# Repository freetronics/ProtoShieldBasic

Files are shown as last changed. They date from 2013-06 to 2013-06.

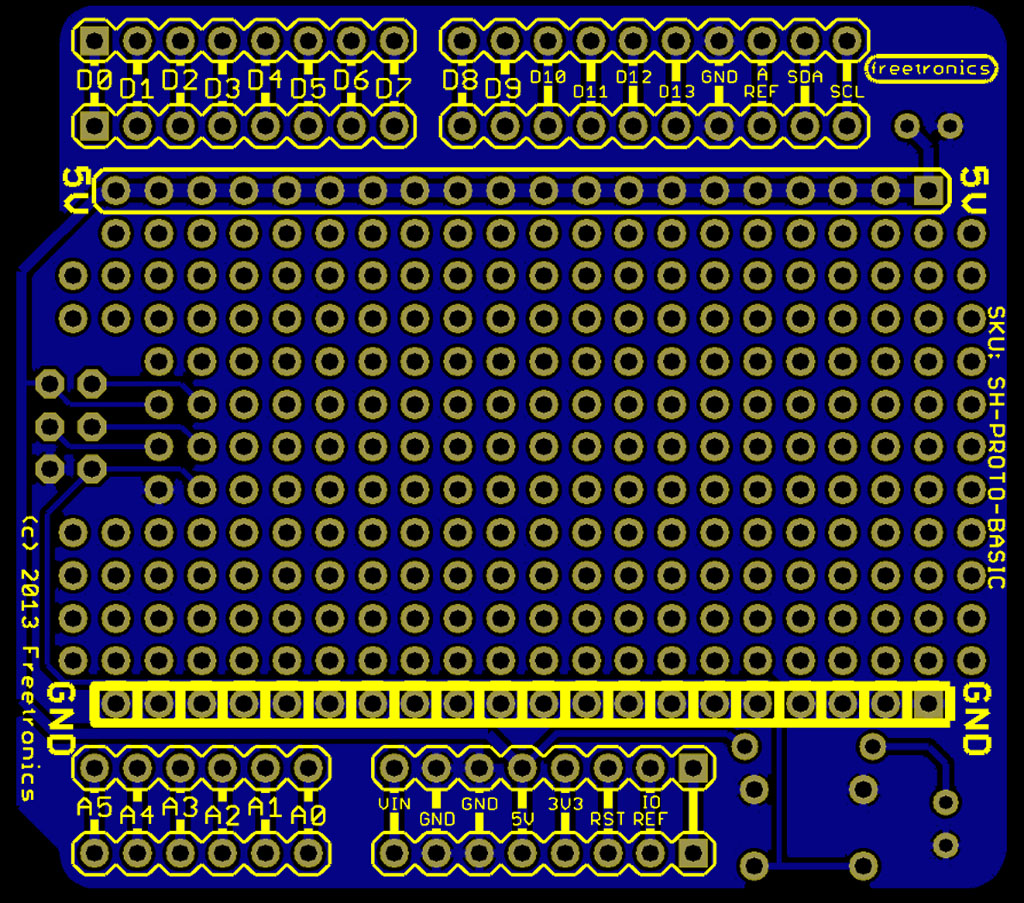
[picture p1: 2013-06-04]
docs/SH-PROTO-BASIC-bottom.jpg

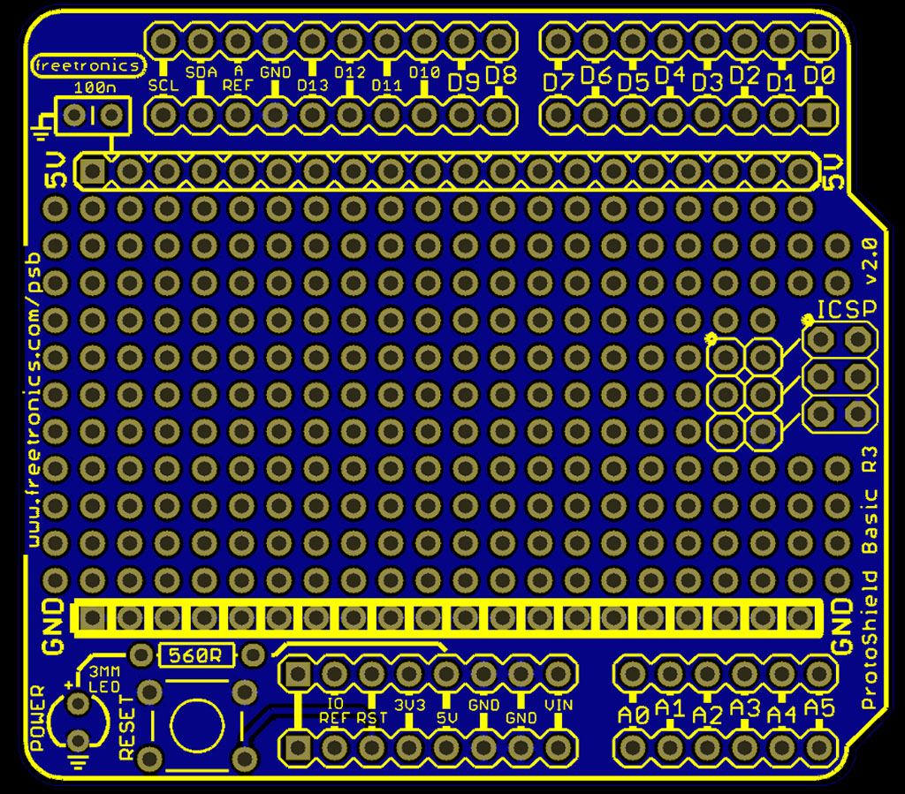
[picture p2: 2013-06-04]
docs/SH-PROTO-BASIC-top.jpg

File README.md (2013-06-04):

Freetronics ProtoShieldBasic
==============================
Copyright 2013 Freetronics Pty Ltd  
Freetronics site:  www.freetronics.com  
Freetronics email: info@freetronics.com  

A minimalist general-purpose prototyping shield for the Arduino
Uno, Freetronics Eleven, and other compatible boards based on the same
header format.

This design is intended to maximise prototyping area by extending the
plain pads right to the ends of the board, which also makes it easier
to fit horizontal PCB-mount sockets that need to overlap the edge.

Note that this design is intended for simple fabrication and assembly,
and does not have many of the features of other prototyping shields
such as the "ProtoShield Pro" (also available from Freetronics) such as
general-purpose LEDs.

Features:

 * Pads for reset button connected to Arduino reset pin.
 * Pads for 100nF smoothing capacitor.
 * Pads for "power on" LED and current-limiting resistor.
 * Parts overlay on both the top and the bottom so you can see what you
   are connecting without having to keep turning the board over.

More information is available at:

  http://www.freetronics.com/psb

INSTALLATION
------------
The design is saved as an EAGLE project. EAGLE PCB design software is
available from www.cadsoftusa.com free for non-commercial use. To use
this project download it and place the directory containing these files
into the "eagle" directory on your computer. Then open EAGLE and
navigate to Projects -> eagle -> ProtoShieldBasic.

DISTRIBUTION
------------
The specific terms of distribution of this project are governed by the
license referenced below.

LICENSE
-------
Licensed under the TAPR Open Hardware License (www.tapr.org/OHL).
The "license" folder within this repository also contains a copy of
this license in plain text format.

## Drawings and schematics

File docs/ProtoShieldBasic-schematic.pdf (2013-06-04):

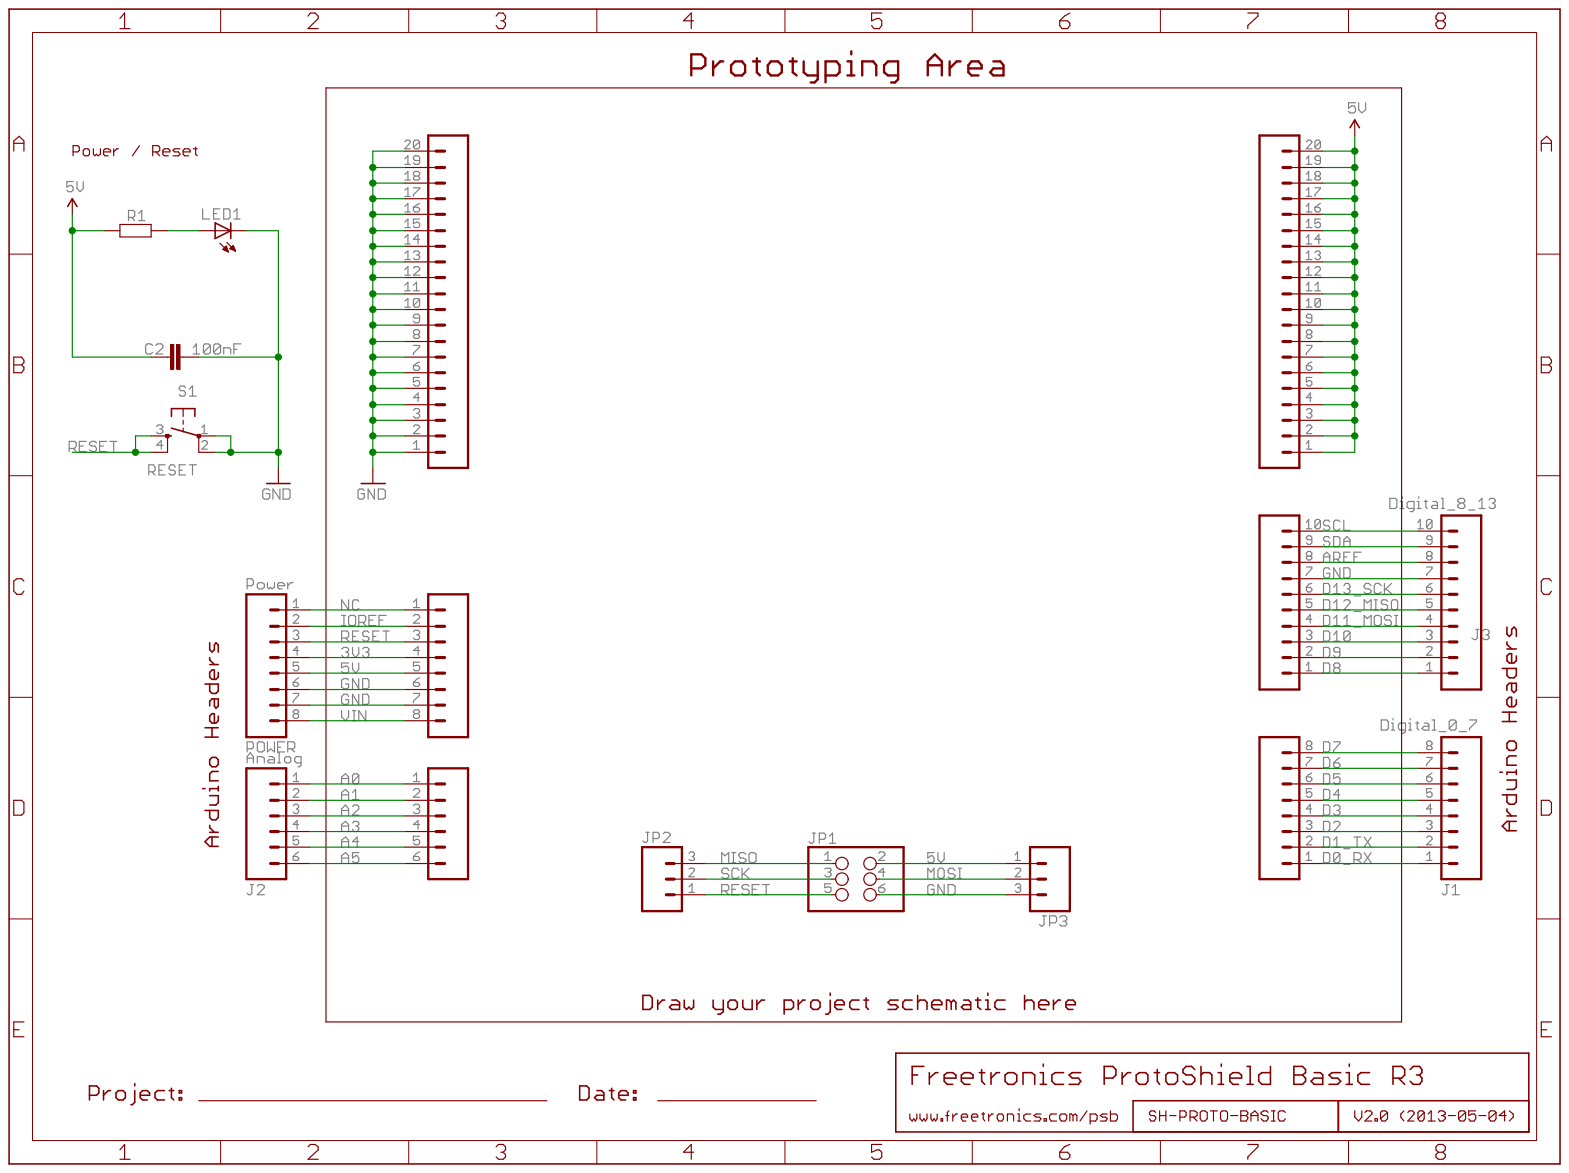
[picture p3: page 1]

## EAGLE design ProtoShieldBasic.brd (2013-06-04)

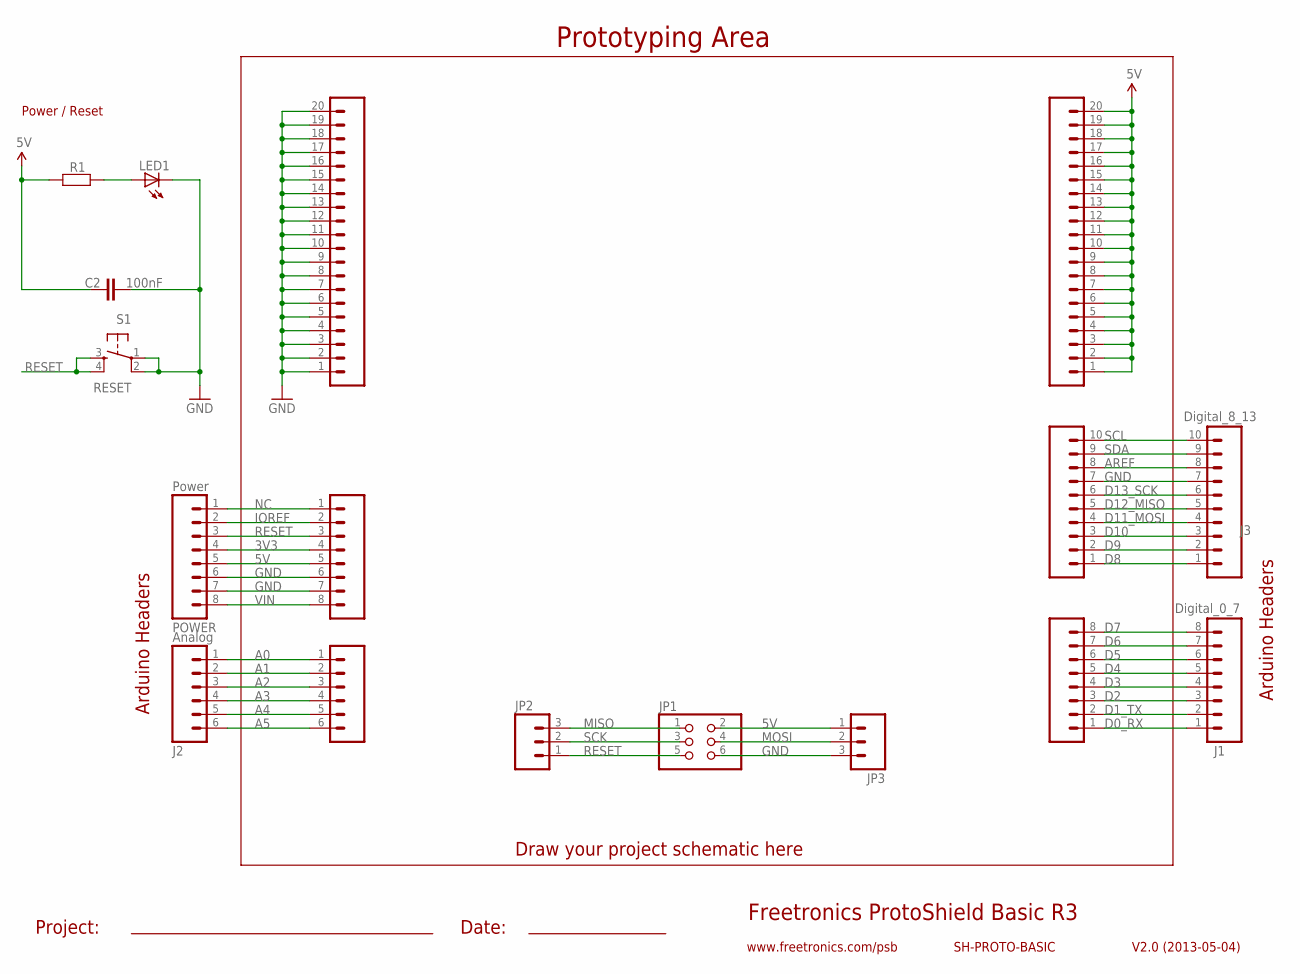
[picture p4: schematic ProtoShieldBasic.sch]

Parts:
C2: 100nF; CAP-PTH-SMALL
J1: Digital_0_7; 1X08
J2: Analog; 1X06
J3: Digital_8_13; 1X10
JP1: PINHD-2X3; 2X03
JP2, JP3: M03PTH; 1X03
LED1: LED3MM
PADS_5V: M20; 1X20
PADS_GND: M20; 1X20
POWER: Power; 1X08
R1: RESISTORPTH1; AXIAL-0.3
S1: RESET; TACTILE-PTH
SL1: Digital_0_7; 1X08
SL2: Analog; 1X06
SL3: Digital_8_13; 1X10
SLP: Power; 1X08

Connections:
3V3: POWER.4, SLP.4
5V: C2.1, JP1.2, JP3.1, PADS_5V.1, PADS_5V.2, PADS_5V.3, PADS_5V.4, PADS_5V.5, PADS_5V.6, PADS_5V.7, PADS_5V.8, PADS_5V.9, PADS_5V.10, PADS_5V.11, PADS_5V.12, PADS_5V.13, PADS_5V.14, PADS_5V.15, PADS_5V.16, PADS_5V.17, PADS_5V.18, PADS_5V.19, PADS_5V.20, POWER.5, R1.P$1 (1), SLP.5
A0: J2.1, SL2.1
A1: J2.2, SL2.2
A2: J2.3, SL2.3
A3: J2.4, SL2.4
A4: J2.5, SL2.5
A5: J2.6, SL2.6
AREF: J3.8, SL3.8
D0_RX: J1.1, SL1.1
D1_TX: J1.2, SL1.2
D2: J1.3, SL1.3
D3: J1.4, SL1.4
D4: J1.5, SL1.5
D5: J1.6, SL1.6
D6: J1.7, SL1.7
D7: J1.8, SL1.8
D8: J3.1, SL3.1
D9: J3.2, SL3.2
D10: J3.3, SL3.3
D11_MOSI: J3.4, SL3.4
D12_MISO: J3.5, SL3.5
D13_SCK: J3.6, SL3.6
GND: C2.2, J3.7, JP1.6, JP3.3, LED1.K (C), PADS_GND.1, PADS_GND.2, PADS_GND.3, PADS_GND.4, PADS_GND.5, PADS_GND.6, PADS_GND.7, PADS_GND.8, PADS_GND.9, PADS_GND.10, PADS_GND.11, PADS_GND.12, PADS_GND.13, PADS_GND.14, PADS_GND.15, PADS_GND.16, PADS_GND.17, PADS_GND.18, PADS_GND.19, PADS_GND.20, POWER.6, POWER.7, S1.1, S1.2, SL3.7, SLP.6, SLP.7
IOREF: POWER.2, SLP.2
MISO: JP1.1, JP2.3
MOSI: JP1.4, JP3.2
unnamed: LED1.A, R1.P$2 (2)
NC: POWER.1, SLP.1
RESET: JP1.5, JP2.1, POWER.3, S1.3, S1.4, SLP.3
SCK: JP1.3, JP2.2
SCL: J3.10, SL3.10
SDA: J3.9, SL3.9
VIN: POWER.8, SLP.8

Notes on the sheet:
Freetronics ProtoShield Basic R3
V2.0 (2013-05-04)
www.freetronics.com/psb
SH-PROTO-BASIC
Prototyping Area
Arduino Headers
Power / Reset
Project:
Date:
Draw your project schematic here

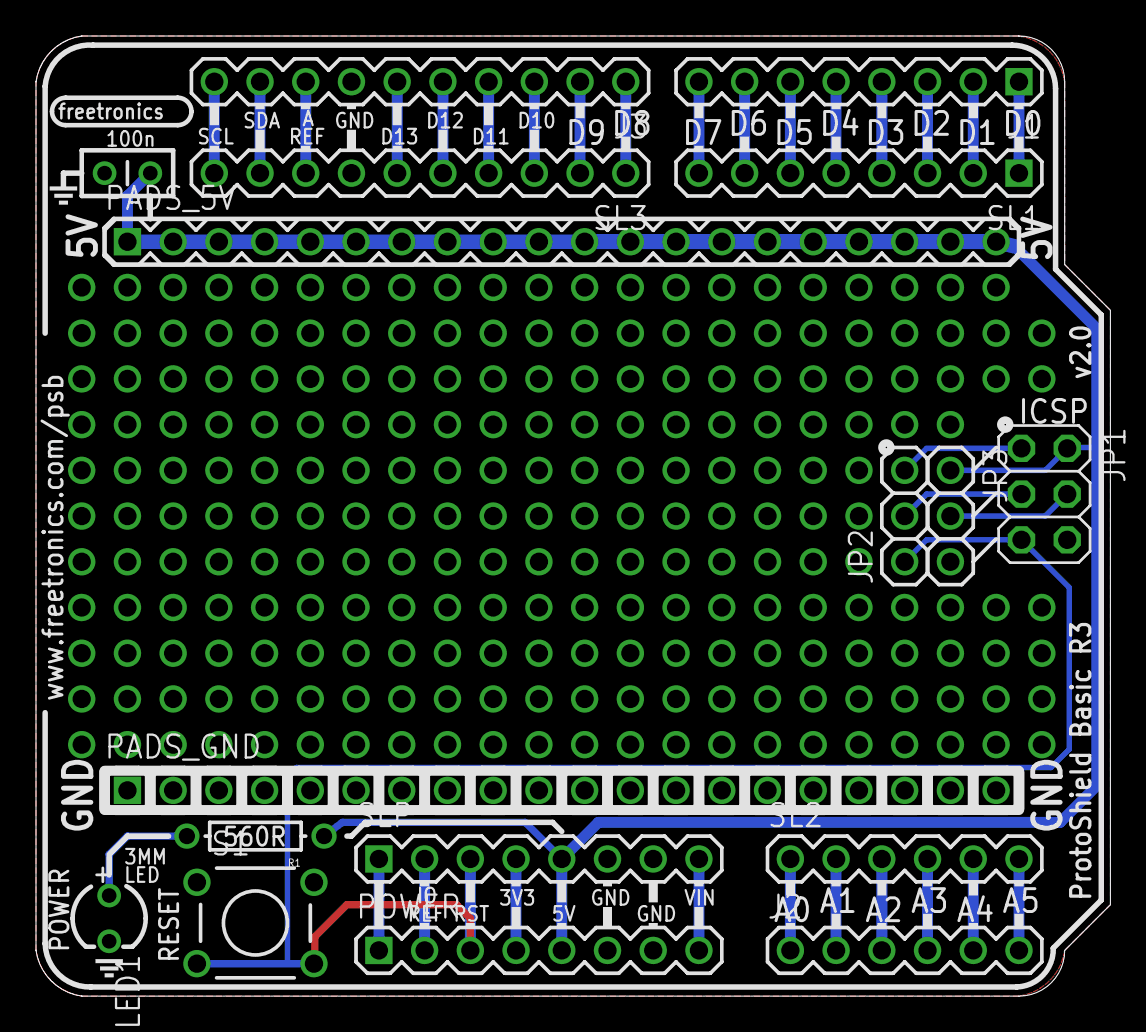
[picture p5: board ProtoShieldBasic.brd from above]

Board: 2 copper layers, 59.7 x 53.3 mm, 17 parts (0 on the bottom side), 34 nets.

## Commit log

2010-05-09 Initial version of project
    [ProtoShieldBasic.brd, ProtoShieldBasic.sch]
2010-05-10 Simplified schematic and adjusted routing
    [ProtoShieldBasic.brd, ProtoShieldBasic.sch]
2010-05-10 Fixed location of 100n label
    [ProtoShieldBasic.brd]
2010-05-10 Updated README to reflect part positions provided on the PCB
2010-05-10 Trivial tweaks to track sizes
    [ProtoShieldBasic.brd]
2010-05-10 Fixed positions of misplaced net labels
    [ProtoShieldBasic.sch]
2010-05-12 Added second decoupling cap and reduced length of power rails
    [ProtoShieldBasic.sch]
2010-05-12 Switch position of power rails and updated routing
    [ProtoShieldBasic.brd]
2010-05-14 Trivial tweaks to overlay
    [ProtoShieldBasic.brd]
2010-05-20 Tiny tweak to overlay position
    [ProtoShieldBasic.brd]
2010-05-20 Updated document name and version
    [ProtoShieldBasic.sch]
2010-06-01 Generalised part designators
    [ProtoShieldBasic.brd, ProtoShieldBasic.sch]
2010-06-01 Added PDF of schematic
2010-06-02 sch url edit
    [ProtoShieldBasic.sch]
2010-06-02 pcb artwork edit
    [ProtoShieldBasic.brd, ProtoShieldBasic.sch]
2010-06-02 Restructured schematic as a worksheet template
    [ProtoShieldBasic.sch]
2010-06-02 Increased label sizes on overlay
    [ProtoShieldBasic.brd]
2010-06-02 Adjusted position of prototyping area
    [ProtoShieldBasic.sch]
2010-06-02 Overlay text on RHS made a little larger
    [ProtoShieldBasic.brd]
2010-06-02 Moved supporting parts to left side of schematic
    [ProtoShieldBasic.sch]
2010-06-03 Release candidate
    [ProtoShieldBasic.brd, ProtoShieldBasic.sch]
2012-02-01 Updated headers to R3 format
    [ProtoShieldBasic.brd, ProtoShieldBasic.sch]
2013-06-04 Release v2.0 with R3 headers
    [ProtoShieldBasic.brd, ProtoShieldBasic.sch]

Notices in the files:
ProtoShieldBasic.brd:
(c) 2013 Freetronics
